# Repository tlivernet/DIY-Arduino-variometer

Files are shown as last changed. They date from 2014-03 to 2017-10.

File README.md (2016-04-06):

DIY Arduino variometer - with BMP085 Barometric Pressure Sensor
==================

Il s'agit de la version utilisant le capteur de pression BMP085. 
Vous trouverez une version alternative de ce code supportant le MS5611 sur la branche "[MS5611](https://github.com/sinseman/DIY-Arduino-variometer/tree/MS5611)".

- [Mise à jour](#mise-à-jour)
- [Présentation](#présentation)
- [Schéma](#schéma)
- [Installation](#installation)
- [Interface et utilisation](#interface-et-utilisation)

## MISE À JOUR

**Attention !** Lors de la dernière mise à jour le schéma de connection de l'écran a été modifié pour des soucis d'optimisations du montage.

- **PIN\_SCLK** : D8 --> D4
- **PIN\_LIGHT** : D11 --> Inchangée
- **PIN\_SCE** : D7 --> Inchangée
- **PIN\_RESET** : D6 --> D8
- **PIN\_DC** : D5 --> D6
- **PIN\_SDIN** :  D4 --> D5

Bien sûr vous pouvez adapter le code suivant l'ordre des branchements de l'écran à votre disposition.

Cela est valable aussi avec l'encodeur digital pour inverser le sens de rotation en remplaçant ```
Encoder knob(3, 2);``` par ``` Encoder knob(2, 3);```

**Il faut également ré-initialiser la mémoire EEPROM en téléversant une première fois avec la variable initialisation à true puis re-téléverser avec initialisation à false (voir partie [Installation](#installation)).**

## Présentation
### Vidéo de démo

Youtube - DIY - Variomètre à base d'Arduino nano (http://www.youtube.com/watch?v=KeNAhEgbHnc)

[Participer à la discussion sur le forum parapentiste.](http://www.parapentiste.info/forum/bons-plans/variometre-maison-a-base-darduino-t33538.0.html)

### Matériel et coût

Le but de ce projet est de fabriquer un variomètre à faible coût pour une utilisation en vol libre (dans mon cas la pratique du parapente).
Voici à titre indicatif le matériel utilisé et leur prix d'achat sur eBay international (prix de janvier 2014) :

- Arduino nano V3.0	| 5,10€
- Nokia LCD 5110 | 2€
- BMP085 Digital Barometric Pressure Sensor	| 2,90€
- Digital Push Button Switch Rotary Encoder	| 4,20€
- Mini USB Battery Charging Board 5V | 0,90€
- Buzzer 8 ohm | 0,20€
- DC-DC Converter Step Up 1-5V 500mA | 1,15€
- 3,7V 600mAh LiPo Battery | 3,25€
- RTC Module for Arduino | 1,55€
- 3x 10k Ohm resistor + 1x 120 Ohm resistor | 0,10€
- Right Angle Mini Slide Switch | 0,10€	
- Cables | 3€
- Plastic Electronics Project Box Enclosure DIY 27x60x100mm | 2,40€

**TOTAL	| 26,85 €**

## Schéma

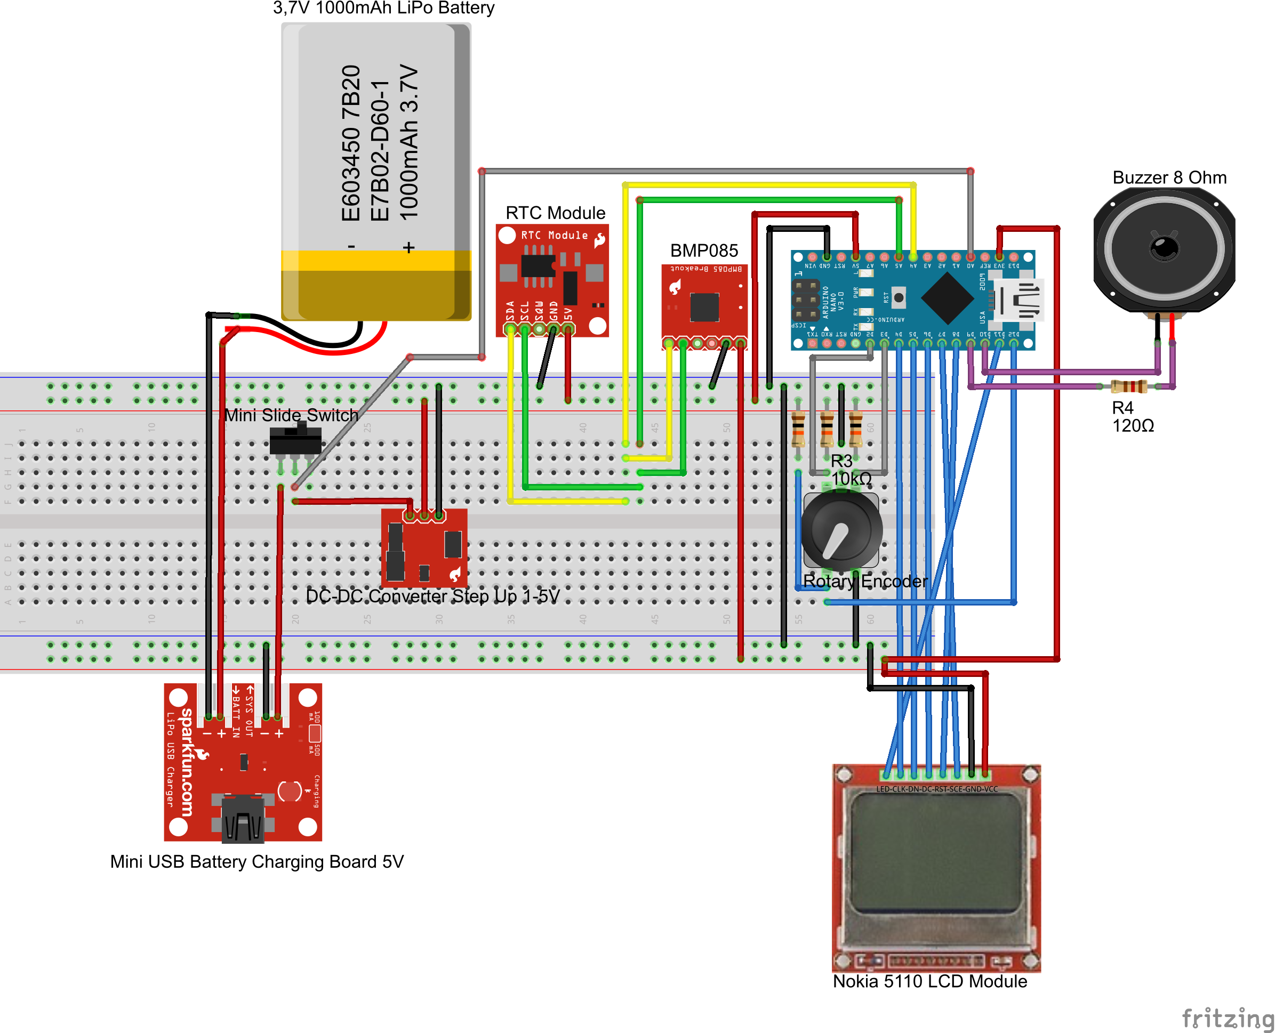
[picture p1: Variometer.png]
Schéma


## Installation

Une fois votre montage terminé il faut compiler et téléverser le code sur votre Arduino. Pour cela il vous faudra utiliser l'IDE Arduino.

**Il faut utiliser [une version de l'IDE Arduino >= 1.5 et <= 1.6.1](https://www.arduino.cc/en/Main/OldSoftwareReleases), sinon des erreurs de compilation apparaissent !**

Tout d'abord vous devez installer les librairies fournies avec le projet. Copiez le contenu du dossier librairies dans le dossier librairies de votre installation (par exemple C:\Users\Toto\Documents\Arduino\libraries)

Ensuite éditez avec l'IDE Arduino le fichier Variometer/Variometer.ino et cliquez sur le bouton "Vérifier" en haut du logiciel. Après un certain temps le message "Compilation terminée" devrait apparaitre. Si vous avez des erreurs vérifiez que les librairies sont bien installées (cf plus haut).

Une fois la compilation OK il faut téléverser le programme sur l'Arduino à l'aide d'un câble USB par exemple et en cliquant sur le bouton "Téléverser" de l'IDE. **Mais avant cela lisez ce qui suit !**

**Lors du premier téléversement du programme sur l'Arduino il est important de mettre dans le code la variable  initialisation à true.
Celle-ci permet d'initisaliser correctement la mémoire Eeprom (stockant les statistiques et les options).**

```
bool initialisation = true; 
```

**Une fois le premier allumage fait il faut donc re-téléverser le code avec cette fois-ci initialisation à false. Si cela n’est pas fait la mémoire Eeprom sera effacée à chaque allumage !**

```
bool initialisation = false; 
```

## Interface et utilisation

Ce variomètre utilise un minimum de commande pour naviguer dans le menu et interagir avec l'interface. Nous utilisons un encodeur digital permettant trois actions: Gauche - Droite - Valider.

L'écran est celui d'un Nokia 5110, donc plutôt petit comparé aux variomètres du commerce, mais les informations essentielles y sont affichées. Ce variomètre produit des "bips" qui sont aussi bien émis lors de la navigation dans le menu que lors de l'utilisation de l'interface vario. 
Le volume est bien entendu paramétrable ainsi que la sensibilité de déclenchement en monté et en descente.

En plus de fournir des informations en temps réel, un système de détection automatique du début et de fin de vol permet d'obtenir des statistiques intéressantes.

### Menu

- Vario
- Stats
	- Retour
	- Statistiques
	- Reset
- Options
	- Retour
	- Tare
	- QNH
	- Alti
	- Montee
	- Desc
	- Light
	- Contra
	- Date

### Vario

Affichage dynamique des éléments suivants :

- Altitude (m)
- Variation d'altitude (m/s) avec jauge dynamique
- Temps de vol (heure : minute : seconde)
- Heure
- Température
- Batterie

Le réglage du volume est possible en tournant l'encodeur digital.
Lors d'un appui long sur le poussoir de l'encodeur, les statistiques sont réinitialisées.

### Stats

L'enregistrement des statistiques de vol se déclenche automatiquement.
Pour cela le variomètre détecte une prise ou une baisse d'altitude significative entrainant le statut "en vol".
Lorsqu'il n'y a pas de baisse ou de prise d'altitude significative pendant un certain temps, le statut "en vol" s'arrête.

A la fin du vol les statistiques sont sauvegardées et ne sont pas perdues à l'extinction du variomètre.

Ce programme peut enregistrer 8 rapports de vol. Une fois un vol terminé, la piste suivante d'enregistrement est sélectionnée. Si celle-ci n'est pas vide elle n'est pas écrasée. Il faut alors manuellement effacer la plage de stat en cours (avec un appui long sur le bouton depuis l'interface Vario) ou reset toutes les plages (Menu Stats --> Reset).

**Statistique**

Voici les informations statistiques disponibles :

- Date
	- Date et heure de début de vol.

- Chrono
	- Temps de vol enregistré, exprimé en heure : minute : seconde.

- AltMin
	- L'altitude minimum en mètre enregistré pendant le vol.

- AltMax
	- L'altitude maximum en mètre enregistré pendant le vol.

- Tx de chutte
	- Les taux de chute maximum et minimum en mètre par seconde enregistrés pendant le vol.

- Cumul
	- Altitude cumulée du vol (en mètre).

**Reset**

Remise à zéro des statistiques.

### Options

**Tare**

Initialise l'altitude zéro sur l'altitude actuelle.

**QNH**

Pression atmosphérique convertie au niveau de la mer selon les conditions de l'atmosphère standard.

**Alti**

Permet d'ajuster l'altitude.

**Montee**

Taux de montée déclenchant le bip.

**Desc**

Taux de descente déclenchant le bip.

**Light**

Intensité du rétro-éclairage (Off à 5)

**Contra**

Ajustement du contraste de l'écran.

**Date**

Réglage de la date et de l'heure de la pendule.

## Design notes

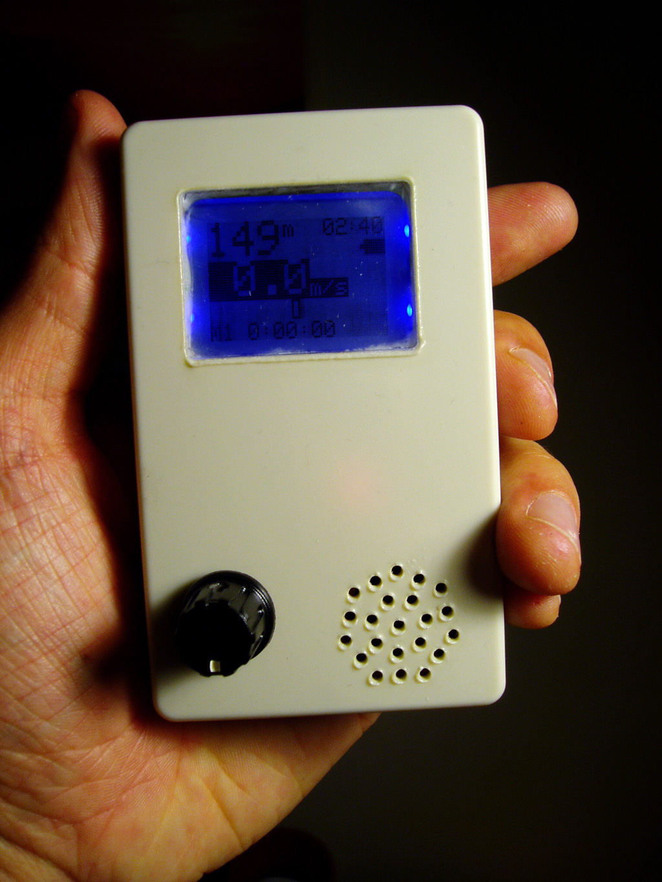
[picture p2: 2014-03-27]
images/face.jpg

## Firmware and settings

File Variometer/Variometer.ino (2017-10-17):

#include <EEPROM.h>
#include <EEPROMAnything.h>
#include <MenuBackend.h>
#include <Encoder.h>
#include <Wire.h>  //i2c library
#include <Adafruit_Sensor.h>
#include <Adafruit_BMP085_U.h>
#include <toneAC.h>
#include <SPI.h>
#include <Adafruit_GFX.h>
#include <Adafruit_PCD8544.h>
#include <RTClib.h>

/////////////////////////////////////////
bool initialisation = false;  //If true, reset and update eeprom memory at arduino start
/////////////////////////////////////////

//////////////////RTC///////////////////////
RTC_DS1307 rtc;
#define DATE_DAY 1
#define DATE_MONTH 2
#define DATE_YEAR 3
#define DATE_HOUR 4
#define DATE_MINUTE 5
uint8_t conf_date_displayed = 0;

uint16_t date_year;
uint8_t date_month;
uint8_t date_day;
uint8_t date_hour;
uint8_t date_minute;
/////////////////////////////////////////

//////////////////ENCODER///////////////////////
#define Enter 12
#define ENCODER_STEP 4

Encoder knob(3, 2);
long knobPosition = 0;
int lastEnterState = HIGH;
/////////////////////////////////////////

//////////////////MENU/////////////////////////
bool menuUsed = false;
bool menuUsed_last = false;
bool varioState = false;
uint8_t stat_displayed = 1;
bool stat_blink_status = false;

#define MENU_RIGHT 0
#define MENU_LEFT 1
#define MENU_VARIO 2
#define MENU_TARE 10
#define MENU_QNH 11
#define MENU_ALTITUDE 12
#define MENU_MONTEE 13
#define MENU_DESCENTE 14
#define MENU_LIGHT 15
#define MENU_CONTRASTE 16
#define MENU_DATE 17
#define MENU_STAT 20
#define MENU_RECRESET 21

//this controls the menu backend and the event generation
MenuBackend menu = MenuBackend(menuUseEvent, menuChangeEvent);

MenuItem m_vario = MenuItem(NULL, MENU_VARIO); //Vario
MenuItem m_options = MenuItem(NULL, MENU_RIGHT); //Options
MenuItem m_stats = MenuItem(NULL, MENU_RIGHT); //Records
MenuItem m_retour = MenuItem(NULL, MENU_LEFT); //Retour

MenuItem m_tare = MenuItem(NULL, MENU_TARE); //Tare
MenuItem m_qnh = MenuItem(NULL, MENU_QNH); //QNH
MenuItem m_altitude = MenuItem(NULL, MENU_ALTITUDE); //Altitude
MenuItem m_montee = MenuItem(NULL, MENU_MONTEE); //Montée
MenuItem m_descente = MenuItem(NULL, MENU_DESCENTE); //Descente
MenuItem m_light = MenuItem(NULL, MENU_LIGHT); //eclairage
MenuItem m_contrast = MenuItem(NULL, MENU_CONTRASTE); //contrast
MenuItem m_date = MenuItem(NULL, MENU_DATE); //date

MenuItem m_retour2 = MenuItem(NULL, MENU_LEFT); //Retour
MenuItem m_stat = MenuItem(NULL, MENU_STAT); //Stat
MenuItem m_recreset = MenuItem(NULL, MENU_RECRESET); //Reset records

/////////////////////////////////////////

//////////////////ECRAN///////////////////////
#define PIN_SCLK  4
#define PIN_LIGHT  11
#define PIN_SCE   7
#define PIN_RESET 8
#define PIN_DC    6
#define PIN_SDIN  5

Adafruit_PCD8544 display = Adafruit_PCD8544(PIN_SCLK, PIN_SDIN, PIN_DC, PIN_SCE, PIN_RESET);
/////////////////////////////////////////

/////////////////////VARIO/////////////////////////
Adafruit_BMP085_Unified bmp085 = Adafruit_BMP085_Unified(10085); //set up bmp085 sensor
#define ALTI_TRIGGER 4 //Trigger to start and stop chrono in meter
float Altitude;
int altitude_temp;
uint8_t chrono_cpt = 0;

float vario = 0;
float vario_old = 0;
float vario_diff = 0;
uint8_t timeNoPauseBeep = 0;
bool noSound = false;
unsigned long get_timeBeep = millis();
uint8_t beepLatency = 0;

bool is_vario_button_push = false;
uint16_t average_vcc = 0;             //variable to hold the value of Vcc from battery
float average_pressure;
unsigned long get_time1 = millis();

uint8_t push_write_eeprom = 6;
float    my_temperature;
float    alt;
float    tim;
float    cumul_alt;

#define memoryBase 32
// Configuration structure (89 bits)
struct Conf
{
  int8_t vario_climb_rate_start;    //minimum climb beeping value(ex. start climbing beeping at 0.4m/s)
  int8_t vario_sink_rate_start;    //maximum sink beeping value (ex. start sink beep at -1.1m/s)
  int currentAltitude;
  uint8_t light_cpt;
  uint8_t contrast_default;
  bool volume;
  float p0;
  uint8_t stat_index;
} conf = {
  3, -11 , 0, 0, 50, true, 1040.00, 0
};

// Statistic structure (112 bits)
#define  NB_STATS 8
struct Stat
{
  uint32_t chrono_start;
  uint16_t chrono;
  int alti_max;
  int alti_min;
  uint8_t txchutemax;
  uint8_t txchutemin;
  uint16_t cumul_alt;
}  stat = {
  0, 0, -20000, 20000, 0, 0, 0
};

float getVarioClimbRateStart()
{
  return (float)conf.vario_climb_rate_start / 10;
}

float getVarioSinkRateStart()
{
  return (float)conf.vario_sink_rate_start / 10;
}

void readStat(uint8_t index = conf.stat_index, Stat &value = stat)
{
  EEPROM_readAnything(sizeof(Conf) + sizeof(Stat) * index, value);
}

void writeStat(uint8_t index = conf.stat_index, Stat &value = stat)
{
  EEPROM_writeAnything(sizeof(Conf) + sizeof(Stat) * index, value);
}

void incrementStatIndex()
{
  conf.stat_index = (conf.stat_index == NB_STATS - 1) ? 0 : conf.stat_index + 1;
  EEPROM_writeAnything(0, conf);
  readStat();
}

void resetStat(uint8_t index = conf.stat_index, bool sound = true)
{
  stat.chrono_start = 0;
  stat.chrono = 0;
  stat.alti_max = -20000;
  stat.alti_min = 20000;
  stat.txchutemax = 0;
  stat.txchutemin = 0;
  stat.cumul_alt = 0;
  writeStat(index);

  altitude_temp = Altitude;

  chrono_cpt = 0;

  if (sound) {
    playConfirmMelody();
  }
}

void resetAllStats()
{
  for (uint8_t i = 0; i < NB_STATS; i++) {
    readStat(i);
    resetStat(i, false);
  }
  conf.stat_index = 0;
  EEPROM_writeAnything(0, conf);
  readStat(0);

  playConfirmMelody();
}

void playConfirmMelody()
{
  if (true == conf.volume) {
    toneAC(700, 500);
  }
}

void resetTimer(unsigned long &timer)
{
  timer = millis();
}

void renderChrono(Stat value = stat)
{
  uint16_t s = (value.chrono == 0 && value.chrono_start != 0) ? rtc.now().unixtime() - value.chrono_start : value.chrono;
  uint8_t h = floor(s / 3600);
  s -= h * 3600;
  uint8_t m = floor(s / 60);
  s -= m * 60;

  display.print(h);
  display.print(F(":"));
  renderZero(m);
  display.print(m);
  display.print(F(":"));
  renderZero((int)s);
  display.print(s);
}

void renderVario()
{
  if (true == varioState) {

    DateTime now = rtc.now();
    display.clearDisplay();

    //ALtitude
    display.setTextColor(BLACK);
    display.setTextSize(2);
    display.print((int)Altitude);
    display.setTextSize(1);
    display.print(F("m"));

    //Time
    display.setCursor(55, 0);
    renderZero(now.hour());
    display.print(now.hour());
    display.setCursor(66, 0);
    display.print(F(":"));
    display.setCursor(72, 0);
    renderZero(now.minute());
    display.print(now.minute());

    //Chrono
    display.setCursor(0, 41);
    display.print(F("M"));
    display.print(conf.stat_index + 1);
    display.print(F(" "));
    renderChrono();

    if (now.second() % 2 == 0) {
      //Battery level
      uint8_t vccPixels = getVccPixels();
      uint8_t bat_x = 72;
      uint8_t bat_y = 9;
      display.drawRect(bat_x + 2, bat_y, 10, 6, BLACK);
      display.fillRect(bat_x, bat_y + 2, 2, 2, BLACK);
      display.fillRect(bat_x + 3 + 8 - vccPixels, bat_y + 1, vccPixels, 4, BLACK);
    }
    else {
      // set up my_temperature
      display.setCursor(62, 9);
      bmp085.getTemperature(&my_temperature);
      display.print((int)my_temperature);
      display.drawPixel(75, 9, BLACK);
      display.drawPixel(76, 9, BLACK);
      display.drawPixel(74, 10, BLACK);
      display.drawPixel(74, 11, BLACK);
      display.drawPixel(75, 12, BLACK);
      display.drawPixel(76, 12, BLACK);
      display.drawPixel(77, 10, BLACK);
      display.drawPixel(77, 11, BLACK);
      display.setCursor(79, 9);
      display.print(F("C"));
    }

    //Vario
    display.setTextColor(WHITE, BLACK);
    display.setCursor(48, 24);
    display.print(F("m/s"));
    display.setTextSize(2);
    display.setCursor(0, 16);

    float vario_abs = abs(vario);
    display.print((vario <= -0.05) ? F("-") : (vario >= 0.05) ? F("+") : F(" "));
    uint8_t m = floor(vario_abs);
    display.print(m);
    display.print(F("."));
    display.print(round(10 * vario_abs) - (10 * m));

    //vario bar
    if (vario >= 0)
      display.fillRect(42, 32, round(abs(vario) * 10), 8, BLACK);
    else
      display.drawRect(42, 32, -round(abs(vario) * 10), 8, BLACK);

    display.display();
  }
}


void renderVolume(bool volume)
{
  display.clearDisplay();
  display.setTextSize(2);
  display.setTextColor(WHITE, BLACK);

  conf.volume = volume;

  push_write_eeprom = 0;
  resetTimer(get_time1); //stop the refresh rendering vario

  display.println(F("Sons:"));
  (false == conf.volume) ? display.print(F("Off")) : display.print(F("On"));
  display.display();
  //playConfirmMelody();
}

float updateConfItem(float var, uint8_t dir = 2, float increment = 1)
{
  // save the configuration if a parameter is validate.
  if (menuUsed_last == true && menuUsed == false) {
    menuUsed_last = false;
    EEPROM_writeAnything(0, conf);
  }
  // otherwise, update the parameter.
  else if (menuUsed) {
    menuUsed_last = menuUsed;
    if  (dir == MENU_RIGHT)
      var += increment;
    else if (dir == MENU_LEFT)
      var -= increment;
  }
  return var;
}

void renderStatItem(float value, const __FlashStringHelper *unit, bool integer = false)
{
  menuUsed = false;
  display.setTextColor(BLACK);

  if (true == integer) {
    display.print((int)value);
  }
  else {
    display.print(value, 1);
  }
  display.print(unit);
}

void renderZero(int value)
{
  if (value <  10)
    display.print(F("0"));
}


void renderDateTime(DateTime d, uint8_t bold = 0)
{
  //display date
  if (bold == DATE_DAY)
    display.setTextColor(WHITE, BLACK);
  renderZero(d.day());
  display.print(d.day());
  
  display.setTextColor(BLACK);
  display.print(F("/"));

  if (bold == DATE_MONTH)
    display.setTextColor(WHITE, BLACK);
  renderZero(d.month());
  display.print(d.month());

  display.setTextColor(BLACK);
  display.print(F("/"));

  if (bold == DATE_YEAR)
    display.setTextColor(WHITE, BLACK);
  renderZero(d.year() - 2000);
  display.print(d.year() - 2000); //reduces the length of the year string

  display.setTextColor(BLACK);
  display.print(F(" "));

  //display time
  if (bold == DATE_HOUR)
    display.setTextColor(WHITE, BLACK);
  renderZero(d.hour());
  display.print(d.hour());

  display.setTextColor(BLACK);
  display.print(F(":"));

  if (bold == DATE_MINUTE)
    display.setTextColor(WHITE, BLACK);
  renderZero(d.minute());
  display.print(d.minute());

  //display.setTextColor(BLACK);
}

void renderMenu(MenuItem newMenuItem = menu.getCurrent(), uint8_t dir = 2)
{
  display.clearDisplay();
  display.setTextSize(1);
  display.setTextColor(WHITE, BLACK);

  if (newMenuItem.getShortkey() != MENU_LEFT) {
    if (newMenuItem.getShortkey() < 10)
      display.println(F("Accueil"));
    else if (newMenuItem.getShortkey() >= 10 && newMenuItem.getShortkey() < 20)
      display.println(F("Options"));
    else if (newMenuItem.getShortkey() == MENU_RECRESET)
      display.println(F("Statistiques"));
  }

  if (newMenuItem.getShortkey() != MENU_STAT) {

    display.setTextSize(2);
    display.println(newMenuItem.getName());

    if (!menuUsed)
      display.setTextColor(BLACK);
  }

  if (varioState == true && menuUsed) {
    varioState = false;
    menuUsed = false;
  }

  //sous-menu (valeur)
  if (varioState == false) {

    switch (newMenuItem.getShortkey()) {

      case MENU_VARIO:
        {
          if (menuUsed) {
            varioState = true;
            menuUsed = false;
          }
        }
        break;

      case MENU_TARE:
        {
          if (menuUsed) {
            menuUsed = false;
            display.print(F("Ok"));

            sensors_event_t event;
            bmp085.getEvent(&event);
            conf.p0 = event.pressure;

            //prevent chrono start and beeping
            resetAltitudeSensor();

            EEPROM_writeAnything(0, conf);
          }
        }
        break;

      case MENU_QNH:
        {
          conf.p0 = updateConfItem(conf.p0, dir, 1);
          //prevent chrono start and beeping
          resetAltitudeSensor();

          display.print(conf.p0);
          display.setTextSize(1);
          display.print(F("hPa"));
        }
        break;

      case MENU_ALTITUDE:
        {
          conf.currentAltitude = updateConfItem(conf.currentAltitude, dir, 5);
          //prevent chrono start and beeping
          resetAltitudeSensor();

          display.print(conf.currentAltitude);
          display.setTextSize(1);
          display.print(F("m"));
        }
        break;


      case MENU_MONTEE:
        {
          conf.vario_climb_rate_start = updateConfItem(conf.vario_climb_rate_start, dir, 1);

          if (conf.vario_climb_rate_start < 1) {
            conf.vario_climb_rate_start = 0;
            display.print(F("Off"));
          }
          else {
            display.print(getVarioClimbRateStart(), 1);
            display.setTextSize(1);
            display.print(F("m/s"));
          }
        }
        break;

      case MENU_DESCENTE:
        {
          conf.vario_sink_rate_start = updateConfItem(conf.vario_sink_rate_start, dir, 1);

          if (conf.vario_sink_rate_start >= 0) {
            conf.vario_sink_rate_start = 0;
            display.print(F("Off"));
          }
          else {
            display.print(getVarioSinkRateStart(), 1);
            display.setTextSize(1);
            display.print(F("m/s"));
          }
        }
        break;

      case MENU_LIGHT:
        {
          conf.light_cpt = updateConfItem(conf.light_cpt, dir, -1);

          if  (conf.light_cpt <= 0)
            conf.light_cpt = 0;

          if (conf.light_cpt >= 5) {
            conf.light_cpt = 5;
            display.print(F("Off"));
          }
          else {
            display.print(5 - conf.light_cpt);
          }
          updateBrightness();
        }
        break;

      case MENU_CONTRASTE:
        {
          conf.contrast_default = updateConfItem(conf.contrast_default, dir, 1);

          if (conf.contrast_default <= 0) {
            conf.contrast_default = 0;
          }
          else if (conf.contrast_default >= 100) {
            conf.contrast_default = 100;
          }

          display.print(conf.contrast_default);
          display.setContrast(conf.contrast_default);
        }
        break;

      case MENU_DATE:
        {
          display.setTextSize(1);

          if (menuUsed_last == false) {

            menuUsed_last = true;

            DateTime now = rtc.now();
            renderDateTime(now);

            date_year = now.year();
            date_month = now.month();
            date_day = now.day();
            date_hour = now.hour();
            date_minute = now.minute();
          }
          else {

            if  (dir != MENU_RIGHT && dir != MENU_LEFT) {

              if (conf_date_displayed < 5) {

                menuUsed_last = true;
                menuUsed = true;
                conf_date_displayed++;
              }
              else {
                menuUsed = false;
                menuUsed_last = true;
                conf_date_displayed = 0;
                rtc.adjust(DateTime(date_year, date_month, date_day, date_hour, date_minute, 0));
                display.setTextColor(BLACK);
                renderDateTime(rtc.now());
              }
            }

            switch (conf_date_displayed) {

              case DATE_DAY:
                if (dir == MENU_RIGHT) (date_day >= 31) ? date_day = 1 : date_day++;
                if (dir == MENU_LEFT) (date_day == 1) ? date_day = 31 : date_day--;
                //display.println(F("Jour"));
                break;
              case DATE_MONTH:
                if (dir == MENU_RIGHT) (date_month >= 12) ? date_month = 1 : date_month++;
                if (dir == MENU_LEFT) (date_month == 1) ? date_month = 12 : date_month--;
                //display.println(F("Mois"));
                break;
              case DATE_YEAR:
                if (dir == MENU_RIGHT) (date_year >= 2099) ? date_year = 2000 : date_year++;
                if (dir == MENU_LEFT) (date_year == 2000) ? date_year = 2099 : date_year--;
                //display.println(F("Annee"));
                break;
              case DATE_HOUR:
                if (dir == MENU_RIGHT) (date_hour >= 23) ? date_hour = 0 : date_hour++;
                if (dir == MENU_LEFT) (date_hour == 0) ? date_hour = 23 : date_hour--;
                //display.println(F("Heure"));
                break;
              case DATE_MINUTE:
                if (dir == MENU_RIGHT) (date_minute >= 59) ? date_minute = 0 : date_minute++;
                if (dir == MENU_LEFT)(date_minute == 0) ? date_minute = 59 : date_minute--;
                //display.println(F("Minute"));
                break;
            }
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
void loop()
{
  readButtons();
  updateAltitude();
  
  float tempo = micros();
  
  /* TEST BLOC */
  //Altitude = alt + 0.05;  
  
  // put it in smooth filter and take average
  vario = vario * 0.8 + (200000 * ((Altitude - alt) / (tempo - tim)));

  /* TEST BLOC */
  /*
  vario = vario + 0.005;
  if (vario > 4)
    vario = 0;
  */

  // Update stats if chrono is running
  if (stat.chrono_start != 0) {

    if (vario > 0)
      cumul_alt += Altitude - alt;

    if (Altitude > stat.alti_max)
      stat.alti_max = Altitude;
    if (Altitude < stat.alti_min)
      stat.alti_min = Altitude;

    int decivario = (int)(vario * 10);
    if (decivario < -stat.txchutemax)
      stat.txchutemax = -decivario;
    if (decivario > stat.txchutemin)
      stat.txchutemin = decivario;
  }

  alt = Altitude;
  tim = tempo;

  // make some beeps...
  makeBeeps();

  //every second
  if (millis() >= (get_time1 + 1000))
  {
    resetTimer(get_time1);
    
    if (menu.getCurrent().getShortkey() == MENU_STAT) {
      menu.use();
    }
    
    // proceedings of the dynamic display of vario
    renderVario();

    // diff with previous variometer measurement
    vario_diff = vario - vario_old;
    vario_old = vario;

    // eeprom saves after 5 seconds
    if (push_write_eeprom == 5) {
      push_write_eeprom++;
      EEPROM_writeAnything(0, conf);
    }
    else if (push_write_eeprom < 5)
      push_write_eeprom++;

    // in vario, if button enter is pressed 1 seconds, reset stats
    if (is_vario_button_push == true) {

      is_vario_button_push = false;
      resetStat();

      display.setTextSize(1);
      display.setTextColor(BLACK);
      display.setCursor(0, 41);
      display.fillRect(0, 41, 84, 7, WHITE);
      resetTimer(get_time1);  //stop the refresh rendering vario
      display.print(F("R.A.Z. stat M"));
      display.print(conf.stat_index + 1);
      display.display();
    }


    // if the altitude out of his "zone", the timer is started
    if (stat.chrono_start == 0) {
      if (altitude_temp + ALTI_TRIGGER < Altitude || altitude_temp - ALTI_TRIGGER > Altitude) {
        resetStat();
        DateTime now = rtc.now();
        stat.chrono_start = now.unixtime();
        chrono_cpt = 0;
        cumul_alt = 0;
      }
      else { // every 15 seconds, the altitude "zone" is updated
        chrono_cpt++;
        if (chrono_cpt >= 15) {
          chrono_cpt = 0;
          altitude_temp = Altitude;
        }
      }
    }
    if (stat.chrono_start != 0 && stat.chrono == 0) {
      // if altitude left in the same "zone" (1.5 meter) during 15 seconds, the timer is stopped
      if (altitude_temp - 0.75 < Altitude && altitude_temp + 0.75 > Altitude) {
        chrono_cpt++;
        if (chrono_cpt >= 15) {
          DateTime now = rtc.now();
          stat.chrono = now.unixtime() - stat.chrono_start;
          stat.cumul_alt = (int)cumul_alt;
          writeStat();
          incrementStatIndex();
        }
      }
      else {
        chrono_cpt = 0;
        altitude_temp = Altitude;
      }
    }
    //correction beep latency
    makeBeeps();
  }
  //Serial.println((tempo - micros()));
}

void readButtons()
{
  long newKnobPosition = knob.read();
  if (newKnobPosition != knobPosition) {
    //Serial.print(newKnobPosition);
    //Serial.print(F(" / "));
    //Serial.println(knobPosition);
    if (abs(newKnobPosition - knobPosition) >= ENCODER_STEP) {
      if (newKnobPosition > knobPosition) { //Right
        if (!menuUsed && varioState == false) {
          if (menu.getCurrent().getShortkey() == MENU_STAT && stat_displayed < NB_STATS) {
            resetTimer(get_time1);
            stat_blink_status = true;
            stat_displayed++;
            renderMenu();
          }
          else
            menu.moveDown();
        }
        else if (varioState == false)
          renderMenu(menu.getCurrent(), MENU_RIGHT);
        else if (varioState == true)
          renderVolume(true);
      }
      else { //Left
        if (!menuUsed && varioState == false) {
          if (menu.getCurrent().getShortkey() == MENU_STAT && stat_displayed > 1) {
            resetTimer(get_time1);
            stat_blink_status = true;
            stat_displayed--;
            renderMenu();
          }
          else
            menu.moveUp();
        }
        else if (varioState == false)
          renderMenu(menu.getCurrent(), MENU_LEFT);
        else if (varioState == true)
          renderVolume(false);
      }
      knobPosition = newKnobPosition;
    }
  }

  //if button enter is pressed
  int reading = digitalRead(Enter);
  if (reading == LOW && lastEnterState == HIGH) {

    // in menu, clic an item
    if (varioState == false) {
      get_time1 = millis() - 1000;
      menu.use();
    }
    // in vario, button enter init timer
    else {
      resetTimer(get_time1);
      is_vario_button_push = true;
    }
  }

  // in vario, stop button enter and go back to menu
  if (reading == HIGH && lastEnterState == LOW && varioState == true && is_vario_button_push == true) {
    is_vario_button_push = false;
    menu.use();
  }

  lastEnterState = reading;

}//end read button

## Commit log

2014-08-28 Update Variometer.ino
    Remplacement de :
    uint8_t percent = round((average_vcc - 3100) * 100 / (4100 - 3100));
    par :
    uint8_t percent = map(average_vcc,3100,4100,0,100);
2014-08-29 Fixed a bug on the stat trigger.
    [Variometer.ino]
2014-09-09 ConfirmMelody lors du changement de volume.
    Rajout d'un son lors du changement du volume. Permet d'aprécier le changement du volume.
2015-02-03 Improved beeps and schema
    [Variometer.fzz]
2015-02-17 Shematic + readme fixes
    [Variometer.fzz]
2017-09-19 Update battery levels
    Issue #4 : mise à jour des tensions de batterie pour les li-ion / li-po actuelles
    + de durée de vie (cycles)
    + de sécu
    [Variometer.ino]
